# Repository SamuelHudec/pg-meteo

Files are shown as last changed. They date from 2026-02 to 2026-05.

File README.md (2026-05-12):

# DIY weather station based on LaskaKit ESP32

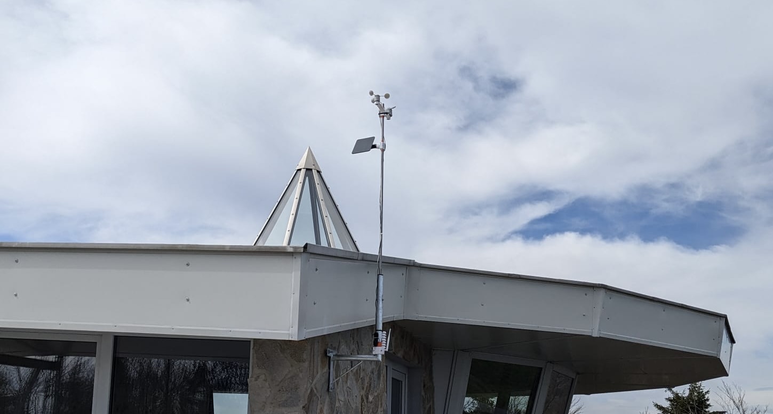
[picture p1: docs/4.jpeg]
DIY weather station


This repository contains the ESPHome configuration and firmware publishing flow for weather stations in this project.

Hardware base board: [LaskaKit Meteo Mini](https://www.laskakit.cz/laskakit-meteo-mini/?variantId=10473)

## Components

Main prototype parts with rough price estimates:

- [LaskaKit Meteo Mini](https://www.laskakit.cz/laskakit-meteo-mini/) - about `398 CZK`
- [GeB LiPol battery 603048 900mAh 3.7V](https://www.laskakit.cz/ehao-lipol-baterie-603048-900mah-3-7v/) - about `100 CZK`
- [WH-SP-WS01 wind speed sensor / anemometer](https://www.laskakit.cz/wh-sp-ws01-cidlo-rychlosti-vetru-anemometr/) - about `228 CZK`
- [WH-SP-WD wind direction sensor](https://www.laskakit.cz/wh-sp-wd-cidlo-smeru-vetru/) - about `288 CZK`
- [LaskaKit SHT40 temperature and humidity sensor](https://www.laskakit.cz/laskakit-sht40-senzor-teploty-a-vlhkosti-vzduchu/) - about `88 CZK`
- [Connfly DS1133-03-S40B RJ11 6/4 connector](https://www.gme.cz/v/1502422/connfly-ds1133-03-s40b-konektor-rj11-6-4) - about `10 CZK`
- [Solar panel 5V 7W with wall mount](https://www.laskakit.cz/solarni-panel-5v-7w-s-drzakem-na-zed/) - about `608 CZK`
- [Pigtail MHF3/IPEX3 to SMA Female, 15cm](https://www.laskakit.cz/pigtail-mhf3-ipex3-sma-female--kabel-1-15mm--15cm/) - about `48 CZK`
- [2.4 GHz antenna 5dBi 19cm](https://www.laskakit.cz/antena-5dbi-19cm-2-4g-bila/) - about `68 CZK`
- [USB-C to JST-PH-2 power cable, 10cm](https://www.laskakit.cz/napajeci-kabel-jq-118j-usb-c-do-jst-ph-2-2mm-10cm/) - about `28 CZK`
- [JST-SH 3-pin cable, 10cm](https://www.laskakit.cz/--sup-io-jst-sh-3-pin-kabel-10cm/) - about `18 CZK`
- [Yageo MFR-25FTE52 metal oxide resistor, 1/4W, 1%](https://www.laskakit.cz/metal-oxidovy-rezistor-yageo-mfr-25fte52-1-4w-1-/?variantId=19979) - about `1 CZK`

Rough total for the listed electronics is about `1,900 CZK`.

This is only a rough parts estimate. It does not include printed parts, fasteners, shipping, or any replacement/alternative components.

3D printable parts are also included in the repository:
- enclosure models in `3D/enclosure/`
- mounting arms and holders in `3D/mount/`

## What the station does

The production device behavior is:

1. Wake up from deep sleep.
2. Power sensors and wait briefly for stabilization.
3. Measure:
   - temperature
   - humidity
   - wind speed
   - wind direction
4. Keep Wi-Fi off during the measurement window to save energy.
5. Aggregate one payload for Windguru:
   - temperature
   - humidity
   - average wind speed
   - maximum wind speed
   - minimum wind speed
   - wind direction
6. Enable Wi-Fi only after measurement is complete.
7. Send the payload to `windguru.cz`.
8. Check the published OTA manifest in this repository.
9. If a newer firmware version is available, download and install it automatically.
10. Go back to deep sleep.

For tuning and debugging, `main.test.yaml` keeps the development-oriented always-on behavior.

## OTA update behavior

In the production config, the device:

1. enables Wi-Fi only after the measurement phase
2. uploads the measured payload after Wi-Fi and time sync are ready
3. checks the published firmware manifest in this repo on each wake cycle
4. if a newer version is available, it downloads and installs the update automatically

The OTA manifest is hosted from this repository and referenced by each station ESPHome config, for example `balcony/esp_config/main.yaml` and `skalka/esp_config/main.yaml`.

## Manual flashing with ESPHome

For a first flash or a recovery flash:

1. Build firmware from this repo or use an already published binary from `skalka/firmware/`.
2. Open `https://web.esphome.io/` in a Chromium-based browser.
3. Connect the ESP32 board over USB.
4. Choose `firmware.factory.bin`
5. Flash the device from the browser UI.

## Firmware publish

Prerequisites:
- Docker deamon is running (if you do not have Docker download and install for your OS)
- `git` and `python3` are installed

Run from repo root:

```bash
./scripts/publish.sh <station>
```

To publish the tuning/test config instead:

```bash
./scripts/publish.sh <station> test
```

Example:

```bash
./scripts/publish.sh skalka
```

What the script does:
1. Compiles `<station>/esp_config/main.yaml` by default, or `<station>/esp_config/main.test.yaml` when `test` is passed as the second argument.
2. Copies built firmware images to:
   - `<station>/firmware/firmware.factory.bin`
   - `<station>/firmware/firmware.ota.bin`
3. Generates `<station>/firmware/manifest.json` with version and md5 hashes.
4. Stages, commits, and pushes firmware artifacts and manifest to `origin/main`.

Note:
- `./scripts/publish.sh <station> test` still publishes to the same `<station>/firmware/` files and manifest as the normal publish flow, so it temporarily replaces the regular published firmware until the next standard publish.
- For quick development checks, use `./scripts/verify.sh <station>` or `./scripts/verify.sh <station> test` instead. It compiles the selected config and validates that OTA and factory binaries were produced, but it does not copy firmware, generate manifests, commit, or push anything.

## Firmware file types

- `skalka/firmware/firmware.factory.bin`: use for first flash, USB flash, browser flash, or recovery flash
- `skalka/firmware/firmware.ota.bin`: use for OTA updates on a device already running ESPHome
- `skalka/firmware/manifest.json`: OTA manifest used by the device to detect and download new firmware

## Local test server

The repository includes a small fake Windguru server for local validation.

Run it from the repo root:

```bash
python3 test_server/fake_windguru_server.py
```

Windows shortcut:

```text
test_server\run_fake_windguru_windows.bat
```

This starts the same fake server and keeps the window open so it is easier to use on a non-developer Windows machine.

It listens on:

```text
http://0.0.0.0:8080/upload/api.php
```

What it does:
- accepts Windguru-like GET requests
- accepts wind fields including `wind_avg`, `wind_max`, `wind_min`, and `wind_direction`
- returns `200 OK`
- logs each request to `windguru_log.jsonl`
- prints a short summary to the terminal

This is useful while validating the measurement and upload flow before switching to the real `windguru.cz` endpoint.

## Current implementation notes

- Wind speed is measured continuously from the anemometer pulse input.
- Wind speed exports include per-window average, maximum, and minimum values.
- Wind direction is derived from the vane resistance through an ADC -> resistance -> heading mapping.
- Temperature and humidity are read from the SHT4x sensor.
- A local/fake Windguru sender currently exists for testing.
- `skalka/esp_config/main.yaml` is the production-oriented config with measure-first, Wi-Fi-late, deep-sleep behavior.
- `skalka/esp_config/main.test.yaml` is the tuning-oriented config with the development behavior.
- The production flow sends one payload per wake cycle, including vector-averaged wind direction.

## Next development ideas

- Rework the production sampling strategy so the reported wind values better represent a full reporting window instead of only one short active period.
- Evaluate a low-power multi-cycle aggregation design:
  - wake up periodically
  - measure briefly with Wi-Fi still disabled
  - keep partial aggregates across sleep cycles
  - upload one payload only after the full time window is complete
- Prefer RTC-retained memory for temporary aggregation state across deep sleep cycles, so the device can avoid frequent flash writes for short-lived measurement data.
- Compare three implementation variants before changing production behavior:
  - deep sleep with RTC-retained aggregation state
  - light sleep between sub-measurements
  - one longer awake measurement window with Wi-Fi disabled until upload

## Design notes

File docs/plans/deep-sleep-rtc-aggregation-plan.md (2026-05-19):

# Deep Sleep RTC Wind Aggregation Plan

## Summary

Create a staged implementation for Skalka production firmware.

The planned behavior is:

- Keep the existing Windguru upload, OTA update check, manifest URL, retry behavior, and firmware publishing flow unchanged.
- Change only the wake/measurement cycle so one Windguru payload represents 5 deep-sleep sub-measurements.
- Use 5 x 12s wind measurement windows per report.
- Use RTC-retained state for temporary wind aggregation across deep sleep, avoiding frequent flash writes.
- Aggregate wind only: average wind speed, min wind speed, max wind speed, and vector-averaged wind direction.
- Leave temperature and humidity as final-cycle sensor snapshots for this first version.

## Implementation Changes

- Add a small RTC aggregation helper for Skalka, preferably `skalka/esp_config/rtc_wind_aggregation.h`, using an `RTC_DATA_ATTR` state struct with:
  - magic/version field
  - completed sub-measurement count
  - wind speed weighted sum
  - wind speed sample count
  - wind speed min/max
  - wind direction sin/cos sums
  - wind direction sample count
  - invalid/reset marker for cold boot, OTA boot, or version mismatch

- Update `skalka/esp_config/main.yaml` measurement flow:
  - On boot, disable Wi-Fi and power sensors as today.
  - Measure wind for `12s` after the existing `sensor_boot_stabilization_delay`.
  - Merge the current wake's volatile measurement stats into RTC aggregation.
  - If fewer than `5` sub-measurements are complete, skip Wi-Fi entirely and enter deep sleep for about `105s`.
  - If the 5th sub-measurement is complete, finalize the RTC aggregate into the existing report sensors, then continue into the existing Wi-Fi, SNTP, Windguru send, OTA check, and sleep path.

- Keep these production areas behaviorally unchanged:
  - `send_windguru`
  - Windguru URL/hash/query construction
  - `update.check` / OTA install logic
  - retry behavior
  - publish and verify scripts
  - firmware manifest structure

- Refactor measurement reset behavior carefully:
  - Per-wake volatile stats reset before each 12s measurement.
  - RTC aggregate reset only after a completed upload flow, a failed final upload flow, or invalid RTC state.
  - Non-final sub-measurement cycles must not clear RTC aggregate.

- Keep rollback practical for a mountain deployment:
  - Increment `fw_version` only when publishing a test or production build.
  - Preserve the last known-good `skalka/firmware/firmware.ota.bin` and `manifest.json` before publishing.
  - Since OTA checks remain unchanged, reverting means republishing the older working firmware/manifest with a newer version string if the station is still reaching Wi-Fi.

## Test Plan

- First implement and validate on `skalka/esp_config/main.test.yaml` or a bench device before production publishing.
- Run:
  - `./scripts/verify.sh skalka test`
  - `./scripts/verify.sh skalka`
- Add temporary INFO logs during validation showing:
  - current sub-measurement number
  - current wake sample counts
  - retained RTC aggregate counts
  - whether the cycle is sleeping without Wi-Fi or performing final upload
  - finalized wind avg/min/max/direction
- Bench-test expected cycle sequence:
  - wake 1-4: measure, merge, no Wi-Fi, deep sleep
  - wake 5: measure, merge, Wi-Fi on, upload path runs, OTA path runs, aggregate resets
- Test cold boot / power loss:
  - RTC state initializes cleanly
  - no bogus aggregate is uploaded
- Test OTA rollback path before mountain deployment:
  - publish test firmware
  - confirm the device can still check the manifest
  - publish older known-good firmware with a newer version string
  - confirm OTA can return the device to older behavior

## Assumptions

- Target reporting cadence remains approximately one payload per 10 minutes.
- The selected sampling shape is 5 x 12s.
- Temperature and humidity remain final-cycle readings in this version.
- RTC-retained state should be implemented with explicit RTC memory rather than ESPHome restored globals, because ESPHome restored globals may save state through the preferences mechanism and the goal is to avoid repeated flash writes.
- ESPHome deep sleep and globals behavior were checked against official docs:
  - https://esphome.io/components/deep_sleep/
  - https://esphome.io/components/globals/

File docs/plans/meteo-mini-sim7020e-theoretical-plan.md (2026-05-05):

# Meteo Mini + SIM7020E Theoretical Plan

This document is a theoretical integration plan for replacing Wi-Fi with an `NB-IoT` modem on the existing `LaskaKit Meteo Mini` weather station.

It is intentionally separate from the current project documentation and does not change the current Wi-Fi based implementation.

## Goal

Use an external `SIM7020E` modem as the uplink for the station so the device can send measurements through an operator network instead of local Wi-Fi.

## Why SIM7020E Looks Interesting

The `SIM7020E` is attractive for this use case because it is:

- low power compared to older GSM modules
- intended for small IoT payloads
- controlled over `UART` with `AT` commands
- suitable for Europe on `NB-IoT`

This makes it a much better fit than `SIM800L` for a battery-powered outdoor sensor.

## What Makes This Different From Wi-Fi

This is not a drop-in hardware swap.

The current station architecture assumes:

- native Wi-Fi on the ESP32-C3
- HTTP upload over the onboard network stack
- OTA checks over Wi-Fi

With `SIM7020E`, the network path changes:

- the ESP32 no longer sends data directly through its own Wi-Fi stack
- the modem must be powered, initialized, registered to the network, and controlled over `UART`
- HTTP or other uplink traffic must be done through modem commands or through a reworked transport layer

## Hardware Feasibility

At a high level, the integration is feasible.

The `LaskaKit Meteo Mini v4.1` exposes:

- `µŠup I2C`: `IO19`, `IO18`
- `µŠup SPI`: `IO3`, `IO7`, `IO6`, `IO2`
- `µŠup IO`: `IO1`, `IO10`

That gives enough usable pins for a simple modem connection.

Important project-specific note:

- `µŠup IO: IO1, IO10` are already occupied by the anemometer and wind direction sensor in the existing station concept

This means those two pins should be treated as unavailable unless the sensor wiring is redesigned.

## Minimal Signal Set

A practical minimum connection would be:

- `TX` from Meteo Mini to modem `RX`
- `RX` from Meteo Mini to modem `TX`
- `GND`
- modem power

Strongly recommended control lines:

- `PWRKEY` or equivalent modem power-on control
- optional `RESET`
- optional `DTR` for sleep control

## Candidate Pin Mapping

This is only a planning suggestion, not a committed wiring standard, and it assumes the current wind sensor assignments would need to change:

| Meteo Mini pin | Suggested modem signal | Notes |
|---|---|---|
| `IO1` | modem `RX` | ESP transmit to modem |
| `IO10` | modem `TX` | ESP receive from modem |
| `IO3` | `PWRKEY` | if SPI is not needed |
| `IO2` | `RESET` or `DTR` | optional control |
| `GND` | `GND` | shared ground |

Alternative mappings are possible depending on which existing peripherals remain attached.

Given the current project wiring, a more realistic direction would be to look for modem control signals on pins exposed through the `µŠup SPI` header, because `IO1` and `IO10` are not free.

## Power Design Concerns

This is the most important hardware risk.

The modem should not be treated like a tiny sensor peripheral.

Key points:

- do not assume the regular `3.3V` peripheral rail is automatically enough
- modem current spikes need to be handled cleanly
- the power path must be validated against the real board design
- shared ground is mandatory

The safest theoretical approach is:

- power the modem from a battery-capable rail that can tolerate burst current
- keep the ESP and modem on a common ground
- add local bulk capacitance near the modem

Before any build, the exact power topology of the chosen `SIM7020E` board should be reviewed carefully.

## Software Impact

This is where most of the work is.

The current project is centered on `ESPHome`, which is great for Wi-Fi sensors but not a natural fit for a cellular modem transport stack.

Expected software consequences:

- `ESPHome` may no longer be the best main runtime if the modem becomes the primary uplink
- upload logic may need to move to custom ESP-IDF or Arduino code
- modem state handling must be added:
  - boot
  - SIM ready
  - network registration
  - PDP/session setup if needed
  - HTTP or MQTT send
  - low-power return
- OTA strategy likely needs redesign

## Architecture Options

There are three realistic paths.

### 1. Keep ESPHome and Add a Custom Modem Bridge

Pros:

- keeps more of the current measurement logic
- smaller conceptual change at first

Cons:

- likely awkward
- modem integration may fight the framework
- OTA and reliability may remain messy

### 2. Rebuild the Node Around ESP-IDF or Arduino

Pros:

- clean control over modem, sleep, retries, and timing
- better long-term fit for `NB-IoT`

Cons:

- larger rewrite
- more engineering effort up front

### 3. Split Responsibilities

Possible idea:

- Meteo Mini remains a measurement node
- a second controller or modem-side board handles uplink

Pros:

- can isolate modem complexity

Cons:

- more hardware
- usually not worth it unless there is a strong reason

## Recommended Direction

If this ever moves from theory to implementation, the most sensible path would likely be:

1. keep the current Wi-Fi station untouched
2. build a separate modem experiment first
3. validate network registration, low-power behavior, and HTTP upload
4. only then decide whether to migrate the full station away from Wi-Fi

This reduces project risk a lot.

## Main Risks

- modem power instability
- poor `NB-IoT` coverage in the exact deployment location
- difficult integration with the current `ESPHome`-based codebase
- higher implementation effort than the hardware simplicity initially suggests
- redesign needed for OTA updates

## Why LoRa Is Still Simpler

Compared with `SIM7020E`, LoRa stays closer to a simple peripheral:

- no SIM card
- no operator dependency
- no network registration sequence
- easier power behavior

That is why LoRa is simpler for a reusable experimental radio layer, even if `NB-IoT` is more attractive from an internet-connectivity perspective.

## Practical Recommendation

Treat `SIM7020E + Meteo Mini` as a separate future branch of the project, not as a small patch to the current design.

If revisited later, the first real prototype should focus only on:

1. modem power and boot
2. UART control
3. network registration
4. one successful payload upload
5. return to low power

Only after that should sensor integration and production firmware migration be considered.

## Reference Links

- LaskaKit Meteo Mini: https://www.laskakit.cz/en/laskakit-meteo-mini/
- Waveshare Pico-SIM7020E wiki: https://www.waveshare.com/wiki/Pico-SIM7020E-NB-IoT
- Waveshare SIM7020E HAT wiki: https://www.waveshare.com/wiki/SIM7020E_NB-IoT_HAT

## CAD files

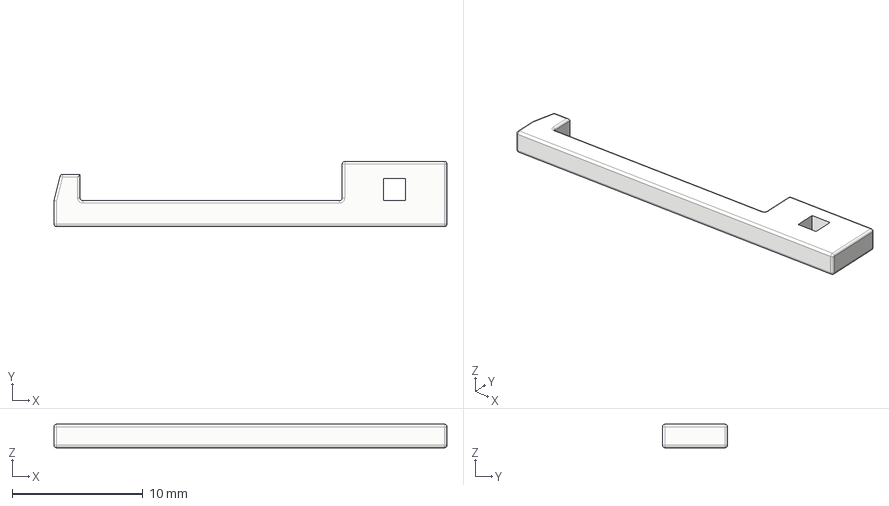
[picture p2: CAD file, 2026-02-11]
3D/enclosure/laskakit_base/switch-pull v1.step
30.0 x 5.00 x 1.80 mm

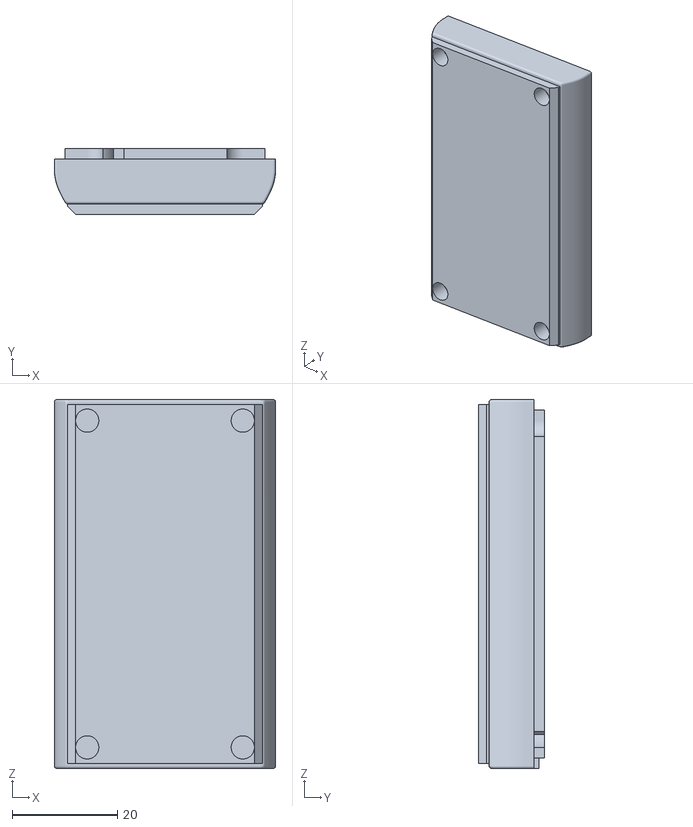
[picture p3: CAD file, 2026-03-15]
3D/enclosure/V2_top.stl
42.0 x 12.5 x 70.0

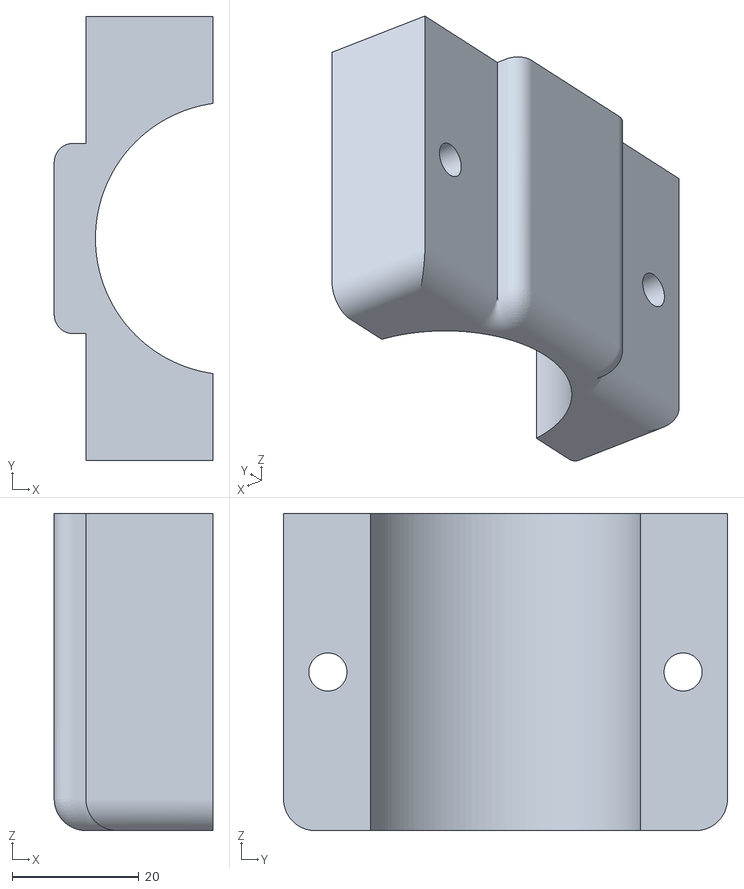
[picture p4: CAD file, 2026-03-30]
3D/mount/UNIVERSAL_HOLDER_42.stl
25.0 x 70.0 x 50.0

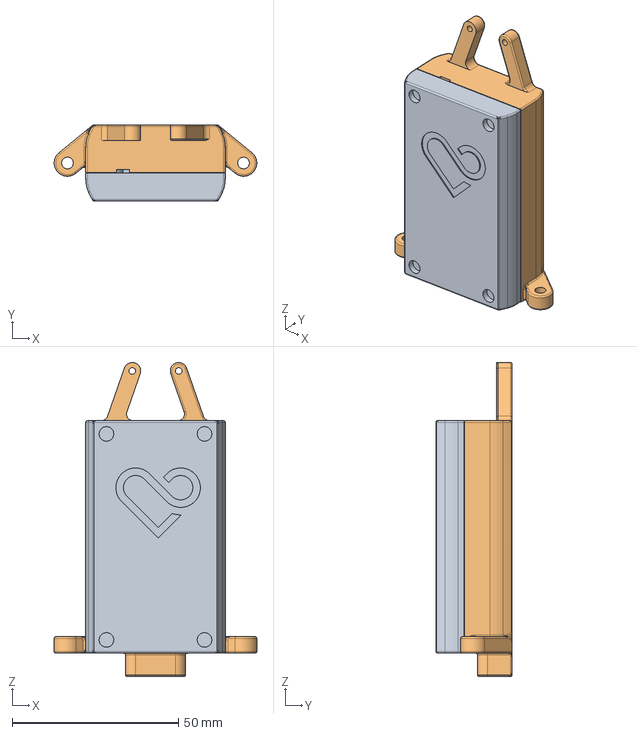
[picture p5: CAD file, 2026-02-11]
3D/enclosure/laskakit_base/enclosure.step
61.0 x 23.0 x 94.5 mm
top
bottom

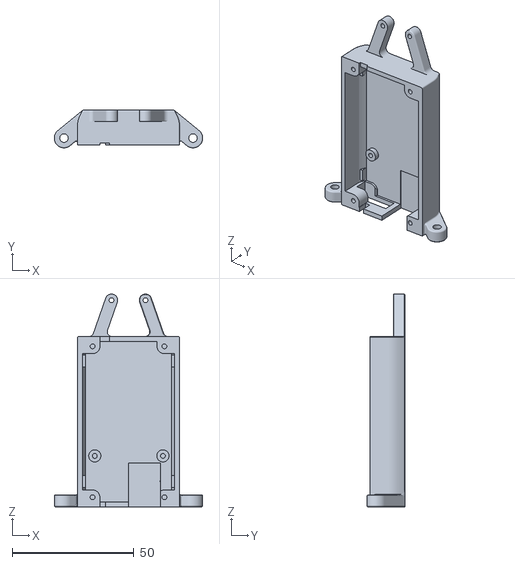
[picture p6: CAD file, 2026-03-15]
3D/enclosure/V2_bottom.stl
61.0 x 15.5 x 87.5

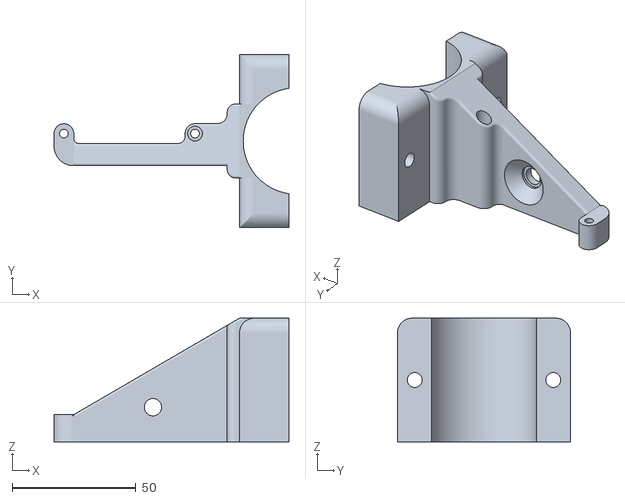
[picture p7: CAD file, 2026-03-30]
3D/mount/METEO_ARM_42.stl
95.0 x 70.0 x 50.0

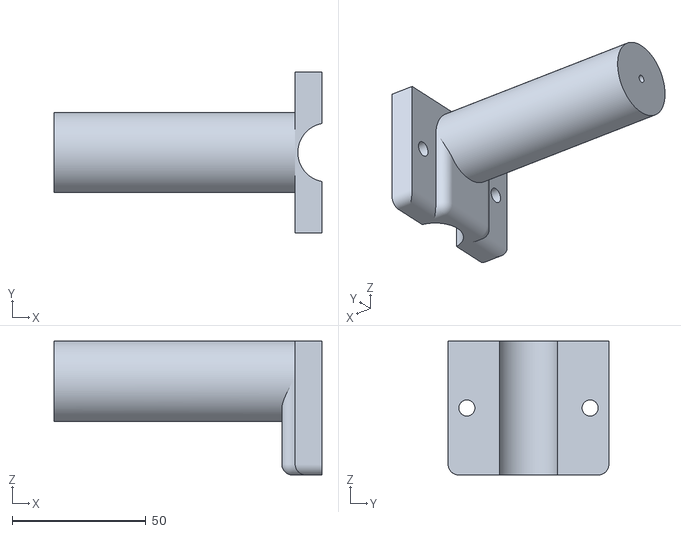
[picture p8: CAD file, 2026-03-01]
3D/mount/SOLAR_ARM.stl
100.0 x 60.0 x 50.0

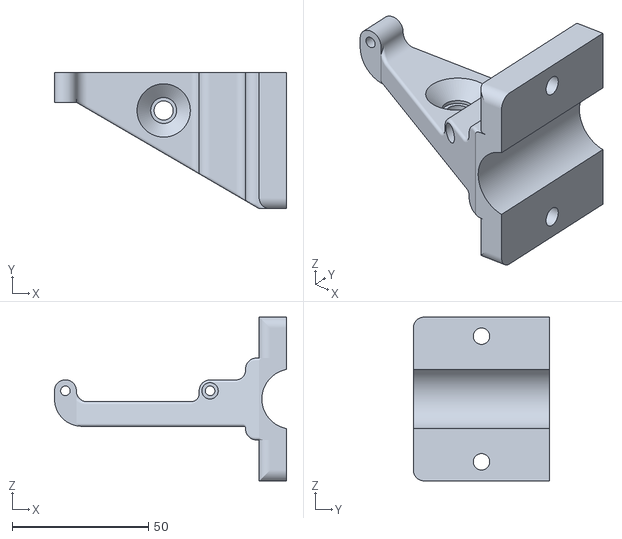
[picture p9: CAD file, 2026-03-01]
3D/mount/METEO_ARM.stl
85.0 x 50.0 x 60.0

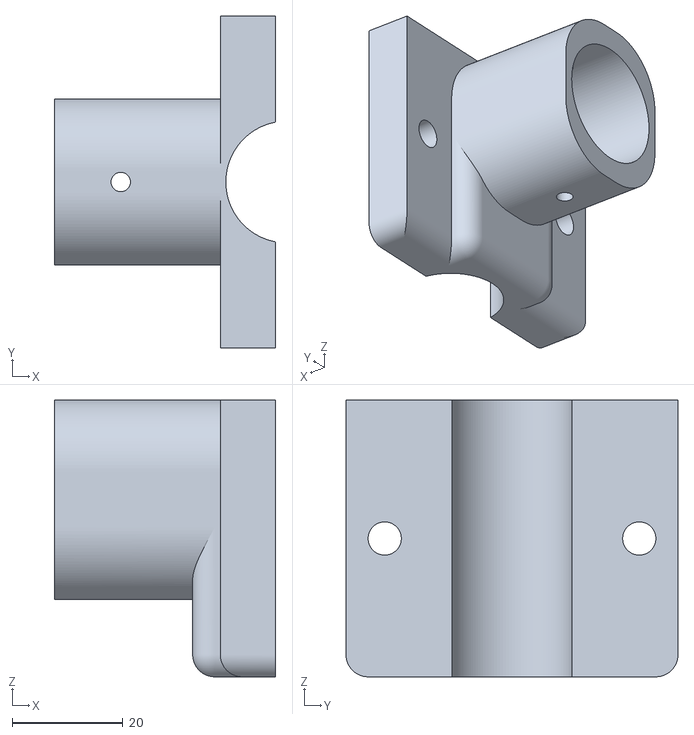
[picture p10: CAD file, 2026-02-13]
3D/mount/SOLAR_SOCKET.stl
40.0 x 60.0 x 50.0

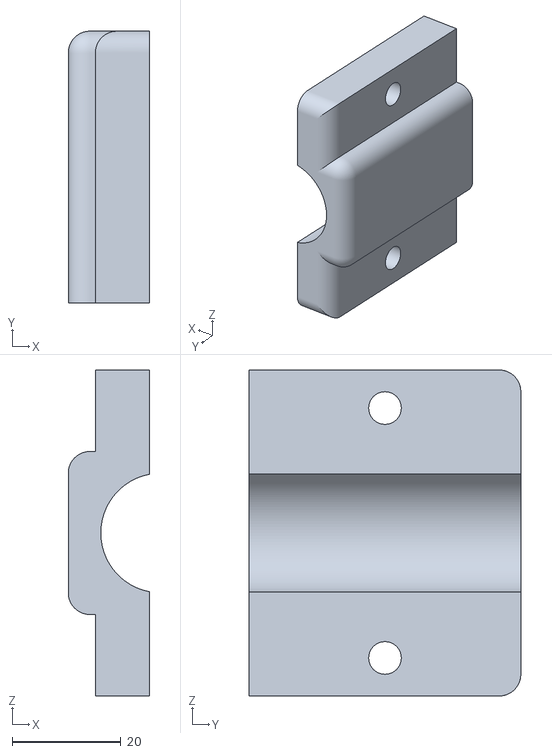
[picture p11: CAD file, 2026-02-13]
3D/mount/UNIVERSAL_HOLDER.stl
15.0 x 50.0 x 60.0

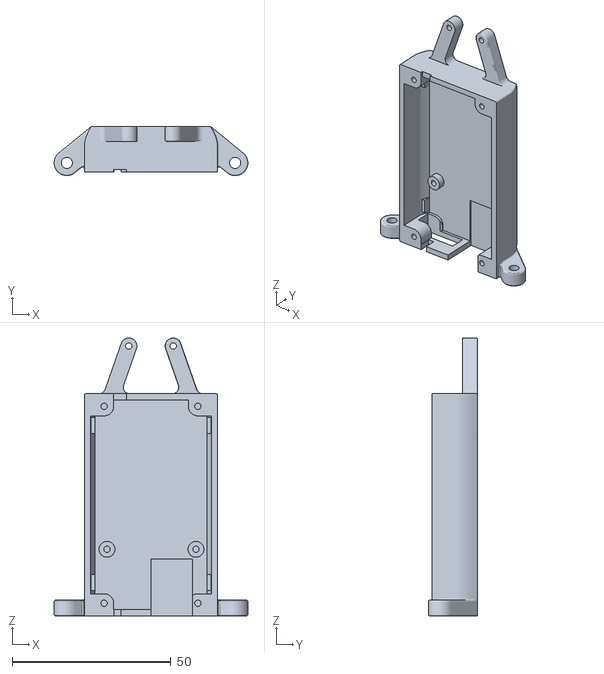
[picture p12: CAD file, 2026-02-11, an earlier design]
3D/enclosure/V1_bottom.stl
61.0 x 15.5 x 87.5

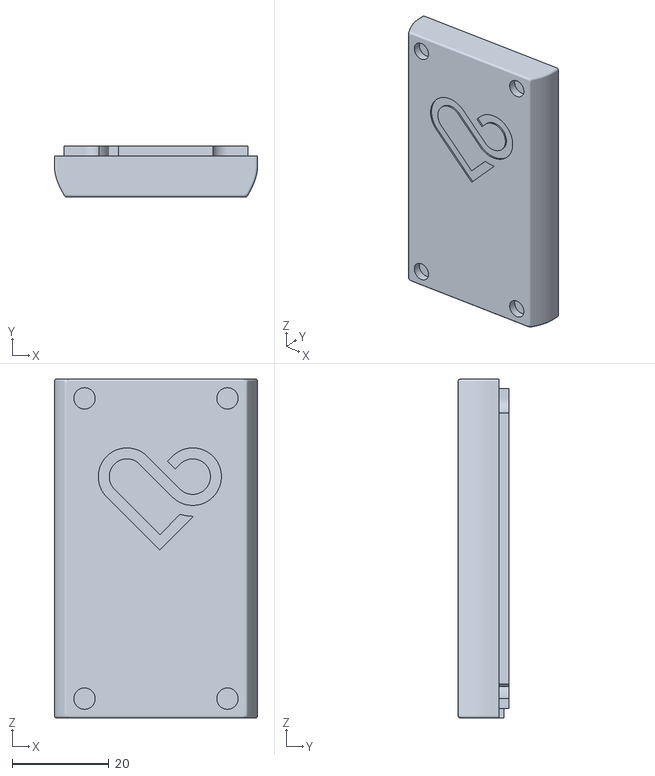
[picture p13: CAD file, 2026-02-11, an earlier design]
3D/enclosure/V1_top.stl
42.0 x 10.5 x 70.0

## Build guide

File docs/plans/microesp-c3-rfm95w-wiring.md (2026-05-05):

# ESP32-C3-LPKit + RFM95W 868 MHz Wiring Guide

This note is a practical wiring guide for building a small universal LoRa radio prototype from:

- `LaskaKit ESP32-C3-LPKit`
- `HopeRF RFM95W 868 MHz`
- `868 MHz antenna`

The goal is a reusable radio block that you can later connect to different ESP-based probes or devices.

## What This Prototype Is

This is not a finished weather station node. It is a reusable `ESP32 + LoRa` base that should let you:

- verify that the radio link works
- send simple packets first
- later attach your own sensors or other logic

For the first bring-up, keep it minimal:

- no sensors
- no battery optimization yet
- no LoRaWAN first
- just `ESP32 <-> RFM95W`

Once this works, everything else becomes much easier.

## Parts

- `LaskaKit ESP32-C3-LPKit`
- `HopeRF RFM95W 868 MHz`
- `868 MHz antenna`
- short wires
- breadboard or perfboard
- optional `10 uF` to `47 uF` electrolytic or ceramic capacitor near the radio module

## Important Safety Notes

- Power the `RFM95W` only from `3.3V`.
- Do not connect any radio pin directly to `5V`.
- Always connect the antenna before transmitting.
- Keep wires between ESP and radio short.
- Make sure `GND` is shared between the board and the radio.

## Recommended Wiring

The `RFM95W` uses `SPI` plus a few control pins. On the `ESP32-C3-LPKit`, the simplest practical setup is to connect the radio over `SPI` and use a few free GPIOs for chip select, reset, and interrupt.

The important idea is:

- use `SPI` for `SCK`, `MISO`, and `MOSI`
- use one GPIO for `NSS` or `CS`
- use one GPIO for `RESET`
- use one GPIO for `DIO0`

Recommended mapping:

| ESP32-C3-LPKit pin | ESP32-C3 GPIO | RFM95W pin | Purpose |
|---|---:|---|---|
| `GPIO4` | 4 | `SCK` | SPI clock |
| `GPIO5` | 5 | `MISO` | SPI MISO |
| `TX` | 21 | `MOSI` | SPI MOSI |
| `GPIO3` | 3 | `NSS` / `CS` | chip select |
| `GPIO2` | 2 | `RESET` | radio reset |
| `RX` | 20 | `DIO0` | interrupt from radio |
| `3V3` | - | `3.3V` | power |
| `GND` | - | `GND` | ground |

Optional later:

| ESP32-C3-LPKit pin | ESP32-C3 GPIO | RFM95W pin | Purpose |
|---|---:|---|---|
| `IO8` on I2C header | 8 | `DIO1` | optional interrupt |

Notes:

- On this board, `SPI` is the correct and recommended way to connect the `RFM95W`.
- The external labels `RX` and `TX` are practical to use as normal GPIO once your firmware is running.
- For the first prototype, `DIO0` is the important interrupt pin. `DIO1` can wait.
- If you prefer, `MOSI` and `DIO0` can be reassigned later in software. The pinout above is just a clean starting point.

## RFM95W Pins You Actually Need

For a first working prototype, connect only these radio pins:

- `3.3V`
- `GND`
- `SCK`
- `MISO`
- `MOSI`
- `NSS` or `CS`
- `RESET`
- `DIO0`

You do not need to wire every pin on the module for the first test.

## Physical Build Order

Build it in this order:

1. Solder or place the `ESP32-C3-LPKit`.
2. Place the `RFM95W` so the SPI wires stay short.
3. Connect `3V3` and `GND` first.
4. Connect `SCK`, `MISO`, `MOSI`.
5. Connect `NSS`, `RESET`, `DIO0`.
6. Connect the antenna.
7. Only then start flashing and testing.

If you add a capacitor, place it close to the radio:

- capacitor `+` to `3V3`
- capacitor `-` to `GND`

This helps when the radio draws short current peaks during transmit.

## Minimal Wiring Checklist

Before power-up, verify:

- `3V3 -> 3.3V`
- `GND -> GND`
- `GPIO4 -> SCK`
- `GPIO5 -> MISO`
- `TX -> MOSI`
- `GPIO3 -> NSS`
- `GPIO2 -> RESET`
- `RX -> DIO0`
- antenna attached

## Suggested Firmware Pin Defines

If you later write firmware in Arduino style, these defines match the wiring above:

```cpp
#define PIN_LORA_SCK   4
#define PIN_LORA_MISO  5
#define PIN_LORA_MOSI  21
#define PIN_LORA_CS    3
#define PIN_LORA_RST   2
#define PIN_LORA_DIO0  20
```

If your library supports an optional `DIO1`, you can later add:

```cpp
#define PIN_LORA_DIO1  8
```

## First Test Strategy

Do not start with LoRaWAN. First prove that the radio hardware works.

Recommended test sequence:

1. Flash a simple `LoRa send hello` example.
2. Verify the module initializes successfully.
3. Send a counter every few seconds.
4. Confirm reception on the other side.
5. Only then add your own payload format.
6. Only after that consider LoRaWAN.

This keeps debugging manageable.

## Why This Pinout Is Good for a Universal Prototype

This layout leaves the prototype easy to reuse:

- SPI is grouped on a small set of pins
- the radio has dedicated `CS`, `RESET`, and `DIO0`
- the I2C header stays mostly free for future sensors
- the radio block can later be moved to another ESP32 board with only firmware pin changes

That makes it a good base for a general-purpose transmitter module.

## Common Mistakes

- powering the radio from `5V`
- transmitting without antenna
- forgetting shared ground
- using long loose wires that make SPI unstable
- trying to debug radio, sensors, and network stack all at once

## Practical Next Step

Once the `RFM95W` arrives, the most sensible next step is:

1. wire exactly the pins above
2. flash a minimal packet transmit test
3. if the radio initializes correctly, freeze this pinout as your standard adapter layout

If you want, the next iteration of this file can include:

- a matching receiver wiring guide
- a minimal Arduino sketch
- a `RadioLib` example based on this exact pinout

## LoRaWAN Coverage Tester Idea

For this project, a very practical next step is not a full weather station node, but a small handheld `LoRaWAN` test gadget.

The main question this device should answer is:

- can the planned weather station location reliably reach an existing `LoRaWAN` gateway

This is important because the long-term goal is to send weather station data to the internet without building a custom `LoRa` receiver.

## Why Build This First

A dedicated test node helps answer the most important deployment question early:

- is there usable `LoRaWAN` coverage at the chosen place

It also gives you a reusable diagnostic tool for:

- comparing multiple mounting locations
- checking antenna orientation effects
- testing near the final enclosure
- validating coverage before building the complete station

This keeps early testing focused on connectivity instead of mixing in sensors, station firmware, and power-management problems.

## Architecture Assumption

This plan assumes the preferred path is:

- use an existing public, community, or commercial `LoRaWAN` network if coverage exists

That means the communication chain should look like:

- `test gadget or weather station -> LoRaWAN gateway -> internet -> application/backend -> Windguru`

So this gadget is not meant to talk to a custom local receiver. It is meant to prove that the chosen site can join and send uplinks through an existing `LoRaWAN` network.

## Suggested V1 Hardware

For the first version, keep it minimal:

- `LaskaKit ESP32-C3-LPKit`
- `HopeRF RFM95W 868 MHz`
- `868 MHz antenna`
- `1 push button` for send
- `1 LED` for status
- optional second LED or buzzer later
- `USB power bank` or USB cable for power during first tests

Do not optimize for final battery life in this phase. The main job is to produce repeatable `LoRaWAN` uplinks.

## Suggested V1 Behavior

The firmware can stay intentionally small:

- on boot, blink the LED to show the device is alive
- try to join the configured `LoRaWAN` network
- indicate join success or failure using the LED
- short button press sends one uplink
- long button press sends multiple uplinks with a small delay between them

Example behavior:

1. boot and attempt network join
2. LED shows whether join succeeded
3. short press sends `1` uplink
4. long press sends `10` uplinks, one every few seconds
5. each uplink increments a counter

This makes field testing easy even without a screen.

## Suggested Payload Content

Each transmitted payload should be easy to inspect in the `LoRaWAN` backend.

Suggested fields:

- `device_id`
- `packet_counter`
- `uptime_ms` or simple time since boot
- `button_mode`
- optional `battery_voltage`

This is enough to confirm:

- the node joined successfully
- uplinks are arriving
- uplinks are not duplicated unexpectedly
- packet loss rate can be estimated
- the device stayed powered and operating correctly

## What To Verify

During field testing, the most useful checks are:

- whether the node can join the `LoRaWAN` network from that place
- whether uplinks appear consistently in the backend
- how often packets are lost
- whether signal quality stays acceptable
- whether moving the device or antenna changes reliability

## What Not To Add Yet

For the first coverage tester, avoid extra complexity:

- no weather sensors yet
- no display unless truly needed
- no battery optimization yet
- no station enclosure constraints yet
- no final weather-station firmware yet

The faster this prototype becomes usable, the faster you can learn whether the planned station location is viable for `LoRaWAN`.

## Recommended Development Path

The most sensible order is:

1. build the `ESP32-C3-LPKit + RFM95W` radio prototype connected over `SPI`
2. add a button and LED
3. choose a target `LoRaWAN` network
4. configure the device for network join
5. test the gadget at home in Prague, where `LoRaWAN` coverage should be much more likely
6. send a known uplink on demand
7. verify uplinks in the network backend
8. once the gadget works reliably at home, test from the planned weather station location
9. only then start integrating `LoRaWAN` into the real weather station design

## Home-First Test Plan

Before going to terrain, first prove that the gadget itself is working in a place where `LoRaWAN` coverage is expected to be available.

The purpose of the home test in Prague is to separate two questions:

- does the gadget and network setup work at all
- does the target field location have enough `LoRaWAN` coverage

This matters because a failure in terrain can otherwise be ambiguous. It may be caused by:

- wrong wiring
- firmware problem
- bad device registration
- antenna issue
- no `LoRaWAN` coverage at the field location

Testing at home first makes debugging much easier.

Recommended home test sequence:

1. power the gadget at home
2. verify that it can join the chosen `LoRaWAN` network
3. press the button and send one uplink
4. confirm that the uplink appears in the backend
5. repeat several times to check reliability
6. try a few positions such as near a window, inside a room, and outside if practical

Only after this works reliably should the same gadget be taken to the planned station location for a real coverage test.

## Result

If this test gadget works well, it becomes a reusable tool for the whole project:

- `LoRaWAN` coverage tester
- bring-up transmitter
- troubleshooting device
- reference hardware for later station integration

## Sources

- LaskaKit ESP32-C3-LPKit product page
- HopeRF RFM95W product page: https://www.laskakit.cz/hoperf-rfm95w-868mhz-komunikacni-modul/

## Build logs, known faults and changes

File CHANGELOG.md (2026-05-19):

# Changelog

Notable project changes are tracked here.

## Unreleased

- Started the project changelog and backfilled Skalka notes from older commit messages.

## 2026-05-19

- Increased the Skalka anemometer pulse debounce filter from `5ms` to `10ms` to reduce false maximum wind speed spikes caused by contact bounce.

## 2026-05-11

- Bumped the Skalka firmware version.
- Added minimum wind speed handling.

## 2026-05-08

- Added median and moving-average filtering for Skalka wind speed readings.
- Updated Skalka Wi-Fi configuration.

## 2026-05-05

- Added planning notes for communication module replacement and version updates.

## 2026-04-20

- Fixed clean output handling.

## 2026-04-19

- Added Windguru upload work for Skalka.
- Added LoRa manual notes and free Wi-Fi notes for Skalka.
- Fixed logging behavior.

## 2026-04-08

- Added first production-oriented Skalka firmware version.

## 2026-03-26

- Fixed Balcony update handling and changed the Skalka IP configuration.

## 2026-03-25

- Raised the Skalka anemometer calibration factor.

## 2026-03-23

- Added anemometer denoising.

## 2026-03-18

- Added Skalka main production config.
- Added the verification script.

## 2026-03-17

- Split Skalka development and production ESPHome configs.
- Added battery level sensor work.
- Polished ignore rules.

## 2026-03-15

- Added average and maximum wind speed handling.
- Reduced log output.
- Updated description and reset button behavior.
- Added enclosure and map updates.

## 2026-03-04

- Expanded ignore rules.

## 2026-03-03

- Added I2C upload work.

## 2026-03-01

- Added HTTP GET testing.
- Added firmware export support and working HTTP update flow.

## 2026-02-13

- Added publish script.
- Added initial Skalka ESPHome config.

## 2026-02-11

- Added initial Skalka sketch.

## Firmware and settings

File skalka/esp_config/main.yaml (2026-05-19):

substitutions:
  device_name: weather-station-skalka
  friendly_name: Weather Station Skalka
  ota_manifest_url: "https://raw.githubusercontent.com/SamuelHudec/pg-meteo/main/skalka/firmware/manifest.json"
  wifi_connect_timeout: 15s
  sntp_sync_timeout: 15s
  ota_check_result_timeout: 8s
  pre_sleep_network_settle_delay: 500ms
  windguru_post_sync_delay: 10s
  windguru_retry_delay: 10s
  sensor_boot_stabilization_delay: 3s
  measurement_duration: 60s
  deep_sleep_failsafe_run_duration: 100s
  deep_sleep_duration: 520s
  fw_version: 0.2.10
  windguru_url: "https://www.windguru.cz/upload/api.php"
  windguru_uid: !secret windguru_uid
  windguru_password: !secret windguru_password
  anemometer_factor: "0.005560619"

esphome:
  name: ${device_name}
  friendly_name: ${friendly_name}
  includes:
    - windguru_auth.h
  project:
    name: samuelhudec.pg_meteo
    version: ${fw_version}
  on_boot:
    priority: 800
    then:
      - wifi.disable:
      - switch.turn_on: i2c_power
      - script.execute: production_cycle
  on_shutdown:
    then:
      - if:
          condition:
            lambda: |-
              return id(ota_install_in_progress);
          then:
            - logger.log: "OTA: install handed off, rebooting"

esp32:
  board: esp32-c3-devkitm-1
  framework:
    type: esp-idf

i2c:
  sda: 19
  scl: 18
  scan: true
  id: bus_a

switch:
  - platform: gpio
    pin: GPIO4
    id: i2c_power
    restore_mode: ALWAYS_ON

button:
  - platform: restart
    name: "${friendly_name} Restart"

logger:
  level: INFO

wifi:
  networks:
    - ssid: !secret wifi_ssid
      password: !secret wifi_password
    - ssid: !secret wifi_ssid_alt
      password: !secret wifi_password_alt
  enable_on_boot: false
  reboot_timeout: 0s

time:
  - platform: sntp
    id: sntp_time

http_request:
  buffer_size_rx: 2048
  timeout: 10s
  follow_redirects: true

ota:
  - platform: esphome
  - platform: http_request
    id: ota_http

update:
  - platform: http_request
    id: fw_update
    name: "${friendly_name} Firmware Update"
    source: ${ota_manifest_url}
    update_interval: never
    on_update_available:
      then:
        - lambda: |-
            id(ota_install_in_progress) = true;
        - logger.log: "OTA: update available, starting update"
        - delay: 3s
        - update.perform: fw_update

deep_sleep:
  id: sleep_ctrl
  run_duration: ${deep_sleep_failsafe_run_duration}
  sleep_duration: ${deep_sleep_duration}

globals:
  - id: wind_speed_sum
    type: float
    restore_value: no
    initial_value: "0.0"
  - id: wind_speed_samples
    type: int
    restore_value: no
    initial_value: "0"
  - id: wind_speed_max_sample
    type: float
    restore_value: no
    initial_value: "0.0"
  - id: wind_speed_min_sample
    type: float
    restore_value: no
    initial_value: "0.0"
  - id: wind_dir_sin_sum
    type: float
    restore_value: no
    initial_value: "0.0"
  - id: wind_dir_cos_sum
    type: float
    restore_value: no
    initial_value: "0.0"
  - id: wind_dir_samples
    type: int
    restore_value: no
    initial_value: "0"
  - id: measurement_active
    type: bool
    restore_value: no
    initial_value: "false"
  - id: ota_install_in_progress
    type: bool
    restore_value: no
    initial_value: "false"
  - id: windguru_retry_pending
    type: bool
    restore_value: no
    initial_value: "false"
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

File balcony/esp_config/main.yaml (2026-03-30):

substitutions:
  device_name: meteo_station
  friendly_name: Meteo station
  ota_manifest_url: "https://raw.githubusercontent.com/SamuelHudec/pg-meteo/main/balcony/firmware/manifest.json"
  wifi_connect_timeout: 15s
  sntp_sync_timeout: 15s
  home_assistant_api_timeout: 5s
  home_assistant_publish_grace_period: 5s
  ota_check_result_timeout: 8s
  pre_sleep_network_settle_delay: 500ms
  sensor_boot_stabilization_delay: 3s
  measurement_duration: 60s
  deep_sleep_failsafe_run_duration: 100s
  deep_sleep_duration: 5min
  fw_version: 0.0.2-dev
  fake_windguru_url: "http://192.168.1.2:8080/upload/api.php"
  fake_windguru_uid: "97411"

esphome:
  name: ${device_name}
  friendly_name: ${friendly_name}
  project:
    name: samuelhudec.pg_meteo
    version: ${fw_version}
  on_boot:
    priority: 800
    then:
      - wifi.disable:
      - script.execute: production_cycle
  on_shutdown:
    then:
      - if:
          condition:
            lambda: |-
              return id(ota_install_in_progress);
          then:
            - logger.log: "OTA: install handed off, rebooting"

esp32:
  board: esp32-c3-devkitm-1
  framework:
    type: esp-idf

logger:
  level: INFO
  hardware_uart: UART0
  baud_rate: 115200

api:
  encryption:
    key: !secret MS_api_encryption_key

wifi:
  ssid: !secret wifi_ssid
  password: !secret wifi_password
  enable_on_boot: false
  reboot_timeout: 0s

time:
  - platform: sntp
    id: sntp_time

http_request:
  buffer_size_rx: 2048
  timeout: 10s
  follow_redirects: true

ota:
  - platform: esphome
    password: !secret MS_ota_password
  - platform: http_request
    id: ota_http

update:
  - platform: http_request
    id: fw_update
    name: "${friendly_name} Firmware Update"
    source: ${ota_manifest_url}
    update_interval: never
    on_update_available:
      then:
        - lambda: |-
            id(ota_install_in_progress) = true;
        - logger.log: "OTA: update available, starting update"
        - delay: 3s
        - update.perform: fw_update

deep_sleep:
  id: sleep_ctrl
  run_duration: ${deep_sleep_failsafe_run_duration}
  sleep_duration: ${deep_sleep_duration}

i2c:
  sda: 19
  scl: 18
  scan: true
  id: bus_a

switch:
  - platform: gpio
    pin: GPIO3
    id: my_output
    restore_mode: ALWAYS_ON

globals:
  - id: ota_install_in_progress
    type: bool
    restore_value: no
    initial_value: "false"

script:
  - id: finish_after_upload
    mode: restart
    then:
      - logger.log: "Cycle: upload finished, checking OTA"
      - update.check: fw_update
      - delay: ${ota_check_result_timeout}
      - if:
          condition:
            lambda: |-
              return id(ota_install_in_progress);
          then:
            - logger.log: "OTA: install in progress"
          else:
            - logger.log: "OTA: no update available"
            - script.execute: enter_production_sleep

  - id: enter_production_sleep
    mode: restart
    then:
      - logger.log: "Cycle: entering deep sleep"
      - delay: ${pre_sleep_network_settle_delay}
      - wifi.disable:
      - delay: ${pre_sleep_network_settle_delay}
      - deep_sleep.enter: sleep_ctrl

  - id: send_fake_windguru
    mode: queued
    then:
      - http_request.get:
          url: !lambda |-
            char buf[384];
            const float temp = isnan(id(meteo_station_Temperature).state) ? 22.5f : id(meteo_station_Temperature).state;
            const float hum = isnan(id(meteo_station_Humidity).state) ? 55.0f : id(meteo_station_Humidity).state;
            const float pressure = isnan(id(meteo_station_Pressure).state) ? 1013.2f : id(meteo_station_Pressure).state;
            const auto now = id(sntp_time).now();
            const long timestamp = now.timestamp;
            const float wind_avg_knots = 0.0f;
            const float wind_max_knots = 0.0f;
            const int wind_dir = 1;
            snprintf(
              buf,
              sizeof(buf),
              "${fake_windguru_url}?uid=${fake_windguru_uid}&interval=60&unixtime=%ld&wind_avg=%.2f&wind_max=%.2f&wind_direction=%d&temperature=%.2f&rh=%.2f&mslp=%.2f",
              timestamp,
              wind_avg_knots,
              wind_max_knots,
              wind_dir,
              temp,
              hum,
              pressure
            );
            return std::string(buf);
          on_response:
            then:
              - lambda: |-
                  ESP_LOGI("windguru", "Windguru send complete: HTTP %d in %u ms", response->status_code, response->duration_ms);
              - script.execute: finish_after_upload
          on_error:
            then:
              - lambda: |-
                  ESP_LOGI("windguru", "Windguru send failed");
              - script.execute: finish_after_upload
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

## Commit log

2026-02-13 init esp config
    [SOLAR_SOCKET.stl, UNIVERSAL_HOLDER.stl, WD_SP_ARM.stl]
2026-03-01 firmware expoert too, working http update
    [METEO_ARM.stl, SOLAR_ARM.stl]
2026-03-03 i2c upload
2026-03-04 ignore more than before
    [washing_machine-left.stl, washing_machine-right.stl]
2026-03-15 new encloser and map
    [V2_bottom.stl, V2_top.stl]
2026-03-15 description and reset button update
2026-03-17 battery level senzor
2026-03-25 balcony revert and skalka factor raise
    [main.test.yaml, main.yaml]
2026-03-26 fix balkony update and chante ip skalka
    [main.test.yaml, main.yaml]
2026-03-29 Implement balcony low-power training workflow
2026-03-30 new models for 42
    [METEO_ARM_42.stl, UNIVERSAL_HOLDER_42.stl]
2026-03-30 switch post with ota update
2026-03-31 flow update
2026-05-05 new plans for comunication module replace and version updates
    [main.test.yaml, main.yaml]
2026-05-08 wind speed median moving average filter
2026-05-19 Increase anemometer debounce filter to reduce false wind speed spikes
